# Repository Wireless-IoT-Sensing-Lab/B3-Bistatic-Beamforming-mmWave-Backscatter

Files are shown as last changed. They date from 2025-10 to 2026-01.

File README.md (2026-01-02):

#  $B^3$: Bistatic Beamforming for mmWave Backscatter

This repository provides the **implementation**, **hardware design**, and **experimental data** for the **Bistatic Beamforming Backscatter ($B^3$)** system — a high-frequency mmWave backscatter tag that enables efficient **beam-steered communication** between transmitters, receivers, and passive backscatter devices.

**📢 Please make sure to cite our paper if you use our hardware design, data, or implementation.**

Zhenzhe Lin, Yoon Chae, Mingyo Jeong, and Parth Pathak, "B^3: Bistatic Backscatter Beamforming for mmWave IoTs", ACM SenSys 2026. 

---

##  Overview

**$B^3$** demonstrates bistatic beamforming techniques that significantly improve **link robustness**, **signal strength**, and **energy efficiency** in mmWave backscatter systems.

This repository includes:
- **Hardware design files** for the custom bistatic backscatter tag and RF front-end — allowing researchers to **reproduce or extend** the hardware design for their own projects.  
- **Hardware Description** detailing each hardware component of $B^3$. Currently detailed descriptions and simulation results of $B^3$ Tx and Rx antennas are available.

---

## 📁 Repository Structure

| Folder | Description |
|:--|:--|
| **/Hardware Description/Antennas.md** | Antenna design documentation, radiation pattern plots, and beamforming test results. |
| **/Hardware Description/Hadamard Matrix.md** | Passive Beamforming Matrix Design documentation. |
| **/PCBO/Readme-PCBO.md** | This document offers a brief description about the PCBO package. |
| **/PCBO/DOCUMENTATION/** | This directory contains the manufacturing document |
| **/PCBO/BILL OF MATERIALS/** | This directory contains the BOM document for those who want to order their own $B^3$ hardware |

---

## Key Features

- **Tag Beamforming** – Coordinated transmit/receive beam control for optimized reflection and link quality.  
- **High-Speed Beam Switching** – Hardware supports up to **40 MHz** beam-switching rate.  
- **Modular Architecture** – Clean separation of control logic, RF front-end, and baseband processing.  
- **Open and Reproducible** – Provides all design files and documents to facilitate reproducibility and future research extensions.

---

**Wireless IoT Sensing Lab**  
[George Mason University]  
[http://www.phpathak.com/]

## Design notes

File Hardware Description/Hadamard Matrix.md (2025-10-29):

# $B^3$ Hadamard Passive Beamforming Matrix Design
A Butler matrix is the most commonly used passive beamformer because it creates a single sharp raditation pattern at a differnet angle depending on the excitation port. However, the angular coverage is typically narrower and, in many in-door applications, multi-beams show  as there is significantly less chance that all main lobes are blockecd by an object. 

**4×4 Hadamard**

A Hadamard matrix generates one center beam and N-1 dual beams at two symmetric angles ($\pm\theta$). This is because the matrix creates $180^\circ$ phase differences between adjacent element groups (or elements).

$$
H_4 =
\tfrac{1}{2}
\begin{bmatrix}
1 & 1 & 1 & 1 \\
1 & -1 & 1 & -1 \\
1 & 1 & -1 & -1 \\
1 & -1 & -1 & 1
\end{bmatrix}
$$

**4×4 Butler matrix**

A Butler matrix generates a pencil beam towards N different angles depending on the excitation port. To broaden the angular coverage, it requires a larget array size. Typically Butler matrix is very hard to implement beyond N=8.

$$
\mathbf{B}_4 =
\tfrac{1}{2}
\begin{bmatrix}
1 & 1 & 1 & 1 \\
1 & \mathrm{j} & -1 & -\mathrm{j} \\
1 & -1 & 1 & -1 \\
1 & -\mathrm{j} & -1 & \mathrm{j}
\end{bmatrix}
$$

## Quadrature hybrid coupler: a building block of a passive beamformer
A **quadrature hybrid** (a 3 dB, 90° branch-line coupler) splits input power equally into two output ports with a **90° phase difference**, while ideally isolating the fourth port. As passive beamformer highly rely on electrical delay differences and power splitting within the RF PCB, a quadrature hybrid coupler is the most important component in many passive beamformers.

**Ideal behavior (port order 1→2 through, 1→3 coupled, 4 isolated):**

<p align="center">
  <a href="https://github.com/user-attachments/assets/1daf9cee-dae2-4ece-bde0-42bf00902120">
    Quadrature hybrid coupler diagram
  </a><br/>
  <em>Figure 1. Quadrature hybrid (90°) coupler diagram. Source: Everything RF.</em>
</p>

$$
\mathbf{S}_\text{ideal}=\tfrac{1}{\sqrt{2}}
\begin{bmatrix}
0 & j & 1 & 0 \\
j & 0 & 0 & 1 \\
1 & 0 & 0 & j \\
0 & 1 & j & 0
\end{bmatrix}
$$

As shown in Figure 1, the four lines are **quarter-wave** sections; a common first cut uses horizontal (series) arms near $Z_0/\sqrt{2}\approx35.4~\Omega$ and vertical (shunt) arms near $Z_0\approx50~\Omega$ (final values are refined in EM to hit amplitude/phase targets). $S_{ideal}$ show the four-port S matrix that shows depending the input port, what are the two output ports and their relative phase differences.

**Quarter-wave physical length:**

$$
\ell_{90}=\frac{\lambda_g}{4}=\frac{c}{4f\sqrt{\varepsilon_\text{eff}}}
$$

As shown in Fig. 1, two $90^\circ$ traces at two different characteristic impedances ($Z_0/\sqrt{2}$, and $Z_0$) are the key design elements. Especially, at millimeter wave (mmWave) beyond 40GHz, $90^\circ$ delay lines are quite tricky to design because of the extremely short wavelength. When wavelength is very short, the $90^\circ$ lines tend to have very short length as compared to the width of the line to meet the impedance requirement. However, that causes phase inaccuracies due to the wide junctions in the vertical traces. To resolve the issue, we uses $Z_0=70.7 \Omega$.

---

**Fine-tuned Quadrature Hybrid Coupler Design**

| <a href="https://github.com/user-attachments/assets/1f7fc1f3-ea8b-4940-ac80-1be1fb2ef35a">Figure 2. The designed microstrip quadrature hybrid coupler</a> | <a href="https://github.com/user-attachments/assets/6d831ed9-ff66-4326-bbdb-1e40fa50c627">Figure 3. The S-parameter (Magnitude)</a> | <a href="https://github.com/user-attachments/assets/57edd651-2c44-4f71-8b04-aeb069404ad9">Figure 4. The S-parameter (Angle) of S21 and S31</a> |
|:--:|:--:|:--:|
| *Figure 2. Quadrature hybrid layout.*<br/>*3 dB, 90° branch-line.* | *Figure 3. S-parameter magnitude.*<br/>*\|S21\| and \|S31\| ≈ 3 dB; \|S11\|/\|S41\| show match & isolation.* | *Figure 4. S-parameter phase (S21 vs S31).*<br/>*Relative phase ≈ 90° across the band.* |

With 5-mil-thick Taconic TLX-8 substrate, line width of 0.1748mm yields the $70.7\Omega$ characteristic impedance while the $90^\circ$ trace width is around 0.85mm. The final length/height ratio is approximately 5; which is a better starting value for good $90^\circ$-phase delay design and -3dB power matching between S21 and S31. The horizontal and vertical branch 
line lengths are tuned to 0.7 and 0.75mm, respectively.

## Microstrip Crossover (using 70.7 Ω, 90° sections)

A **microstrip crossover** lets two transmission lines pass through each other on a single layer while maintaining match and isolation. One practical way at mmWave is to realize it with **$Z_0=70.7~\Omega$ quarter-wave ($90^\circ$) sections**, which provides an all-pass, single-layer structure without vias.

**Ideal 4-port behavior (1↔3, 2↔4), perfectly matched & isolated:**

$$
\mathbf{S}_\text{ideal} =
\begin{bmatrix}
0 & 0 & 1 & 0 \\
0 & 0 & 0 & 1 \\
1 & 0 & 0 & 0 \\
0 & 1 & 0 & 0
\end{bmatrix}
$$

In this ideal, **Port 1 → Port 3** and **Port 2 → Port 4** transmit with unity magnitude (and a defined reference phase), while the adjacent and opposite “non-through” ports are isolated.  
In practice, the 70.7 Ω, $\lambda_g/4$ sections set the electrical lengths so the tee/corner parasitics are absorbed into the phase budget, keeping return loss low and isolation high over the design band.

**Why 70.7 Ω and 90°?**  
The 70.7 Ω choice (i.e., $Z_0\sqrt{2}$ relative to a 50 Ω system) yields practical microstrip widths and allows the crossover to be synthesized as two quadrature paths that re-combine with the desired phase, so each line “sees” a matched through path while the orthogonal coupling is canceled.

---

**Fine-tuned microstrip crossover**

| <a href="https://github.com/user-attachments/assets/ef47e553-3f9d-4816-8d3a-24cd82cba011">Figure 5. The designed microstrip crossover with 70.7Ω, 90° lines</a> | <a href="https://github.com/user-attachments/assets/ffb73675-32cf-4931-bed4-af31b649efbe">Figure 6. S-parameters (magnitude) of the crossover</a> |
|:--:|:--:|
| *Figure 5. Microstrip crossover using $Z_0=70.7~\Omega$ quarter-wave sections.* | *Figure 6. S-parameters (magnitude): through paths (1→3, 2→4) near 0 dB with a small insertion loss; return/isolation low across the band.* |

The fine tuned crossover uses the same line width but the length was tuned to 0.84mm for a high return loss and a low insertion loss.

**Design remarks at 60 GHz:**  
Because $\lambda_g/4$ is short, the **physical $90^\circ$ length can approach pad and junction dimensions**, making the **phase extremely sensitive** to tiny geometry changes. The **70.7 Ω** target keeps line widths practical while balancing junction capacitances, helping the crossover stay matched and maintain isolation without resorting to multilayer vias.

---

## Our 4×4 Hadamard Beamformer Design

<p align="center">
  <a href="https://github.com/user-attachments/assets/50e50b09-91c7-4ba1-aac2-c0a97ddf9c74">
    Figure 7. Final Hadamard matrix design
  </a><br/>
  <em>Figure 7. Final Hadamard beamformer network.</em>
</p>

As shown in Fig. 7, the input ports are impedance-matched to $50~\Omega$ so the designed Hadamard network can connect to an **SP4T (single-pole, four-throw)** RF switch with lower mismatch loss. The output nodes are kept at $70.7~\Omega$ because the antenna is matched to $70.7~\Omega$. The transmission lines in each stage are fine-tuned to realize the target phase distributions. However, due to the impedance sensitivity of the quadrature hybrid coupler, avoiding impedance and phase imbalance is challenging and the tuning requires extensive EM simulations. Our final tuned S-parameter results are below.

---

### Port 1 excitation

| <a href="https://github.com/user-attachments/assets/39da352a-135a-4feb-a7c8-26a1ae7a1d36">Figure 8. S-parameters (magnitude) at Port 1 excitation</a> | <a href="https://github.com/user-attachments/assets/f6167672-8a27-4555-aa94-34bc9b3dc9fe">Figure 9. S-parameters (angle) at Port 1 excitation</a> |
|:--:|:--:|
| *Figure 8. S-parameters (magnitude), Port 1 excitation.* | *Figure 9. S-parameters (angle), Port 1 excitation.* |

### Port 2 excitation

| <a href="https://github.com/user-attachments/assets/ef67fb25-baa7-44d0-bc15-5e74a19fe3b7">Figure 10. S-parameters (magnitude) at Port 2 excitation</a> | <a href="https://github.com/user-attachments/assets/c1f02e03-8fff-4497-82d7-eeee9d60953a">Figure 11. S-parameters (angle) at Port 2 excitation</a> |
|:--:|:--:|
| *Figure 10. S-parameters (magnitude), Port 2 excitation.* | *Figure 11. S-parameters (angle), Port 2 excitation.* |

### Port 3 excitation

| <a href="https://github.com/user-attachments/assets/45a648ec-caec-4e7a-bd6a-d19dc9783381">Figure 12. S-parameters (magnitude) at Port 3 excitation</a> | <a href="https://github.com/user-attachments/assets/b7577b24-5453-41a5-850d-784c350be147">Figure 13. S-parameters (angle) at Port 3 excitation</a> |
|:--:|:--:|
| *Figure 12. S-parameters (magnitude), Port 3 excitation.* | *Figure 13. S-parameters (angle), Port 3 excitation.* |

### Port 4 excitation

| <a href="https://github.com/user-attachments/assets/426ba518-2663-4fc4-be7c-9da0dda3d2d7">Figure 14. S-parameters (magnitude) at Port 4 excitation</a> | <a href="https://github.com/user-attachments/assets/dfd6607b-c0a3-42eb-adc8-a2b0f24ce42b">Figure 15. S-parameters (angle) at Port 4 excitation</a> |
|:--:|:--:|
| *Figure 14. S-parameters (magnitude), Port 4 excitation.* | *Figure 15. S-parameters (angle), Port 4 excitation.* |

**Summary at 60 GHz:** The simulated phase imbalance is approximately within $5^\circ$ at 60 GHz (worst case), and the typical amplitude imbalance is within **1.0 dB** at 60 GHz.

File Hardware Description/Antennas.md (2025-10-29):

# $B^3$ Antenna Designs
Wide beam-coverage is the key factor of successful deployment of $B^3$. For a broader beam coverage and faster beam searching, we choose 4X4 Hadamard beamforming matrix.

$$
H_4 =
\tfrac{1}{2}
\begin{bmatrix}
1 & 1 & 1 & 1 \\
1 & -1 & 1 & -1 \\
1 & 1 & -1 & -1 \\
1 & -1 & -1 & 1
\end{bmatrix}
$$

When a four-linear array antenna is fed by a passive Hadamard beamforming matrix that has the voltage and phase distribution as $H_4$, the array antenna could generate four beam patterns with one center beam and three dual split-beams at two symmetric angles $\pm\theta$.

This document focus on sharing design details of the array antennas we designed for $B^3$. The design of a passive Hadamard beamforming network will be discussed in a separate document.

# Rx Antenna Design

This chapter describes the receive (Rx) antenna used in $B^3$: a single rectangular microstrip patch operating in $TM_{10}$. The choice is deliberate—compared with small arrays it occupies less area, is easy to integrate above a solid ground, and, when pointed broadside at the service region, exhibits a wide, smooth main lobe that behaves like a **pseudo-omnidirectional** pattern for reception.

---

## Electromagnetic model and first-cut dimensions

The patch is treated as a resonant $TM_{10}$ cavity with fringing fields at the radiating edges. Standard closed-form formulas provide a reliable starting point (SI units).

**Patch width (broadside gain and bandwidth improve with larger $W$):**

$$
W=\frac{c}{2f_r}\sqrt{\frac{2}{\varepsilon_r+1}}
$$

**Effective permittivity (accounts for fringing into air):**

$$
\varepsilon_{\mathrm{eff}}
=\frac{\varepsilon_r+1}{2}
+\frac{\varepsilon_r-1}{2}\left(1+12\frac{h}{W}\right)^{-1/2}
$$

**Fringing length extension (per edge):**

$$
\Delta L
=0.412\,h\;
\frac{\left(\varepsilon_{\mathrm{eff}}+0.3\right)\left(\frac{W}{h}+0.264\right)}
{\left(\varepsilon_{\mathrm{eff}}-0.258\right)\left(\frac{W}{h}+0.8\right)}
$$

**Effective and physical length (sets the resonance):**

$$
L_{\mathrm{eff}}=\frac{c}{2f_r\sqrt{\varepsilon_{\mathrm{eff}}}}
$$

$$
L=L_{\mathrm{eff}}-2\Delta L
$$

**Ground plane sizing (keeps the pattern stable):**

$$
W_g \gtrsim W+6h,\qquad L_g \gtrsim L+6h
$$

*Symbols:* $c$ speed of light; $\varepsilon_r$ substrate relative permittivity; $h$ substrate thickness; $W,L$ patch width/length; $f_r$ target resonance.

---

## Why a single patch is a good pseudo-omni **receiver**

Mounted with its broadside facing the coverage region, a rectangular patch has wide half-power beamwidths in both principal planes (commonly on the order of $60^\circ$ – $90^\circ$ depending on $W/L$ and substrate). The integral ground plane suppresses the back lobe and shields cables and electronics, so most sensitivity is directed into the *forward* hemisphere. In dense or indoor environments, multipath and angular spread further “fill in” nulls, making the azimuth response functionally omni-like for receiving while retaining the patch’s compact, low-profile form.

A small footprint does not imply a small receive aperture. Using

$$
A_e=\frac{\lambda^2 G}{4\pi},
$$

a typical broadside gain of $G\approx 6\text{–}8$ dBi yields ample effective area for robust SNR without resorting to an array—useful for $B^3$, where simplicity and repeatability matter.

---

## a 100 Ω inset feed impedance matching

We purposely set the feed point along the patch’s symmetry line where the input resistance is **about $100~\Omega$**. This choice keeps the notch relatively **shallow**, so the $TM_{10}$ current sheet is disturbed less, and the narrower microstrip at the radiating edge adds **less capacitive loading**. Therefore, it preserves the clean broad beam we want for pseudo-omni Rx.

Along the symmetry line, the input resistance varies with inset depth $y$ (measured from the radiating edge) as

$$
R_{\mathrm{in}}(y)=R_{\mathrm{edge}}\cos^{2}\\left(\frac{\pi y}{L}\right).
$$

Solving for a $100~\Omega$ target gives a first-cut inset:

$$
y=\frac{L}{\pi}\cos^{-1}\\sqrt{\frac{100}{R_{\mathrm{edge}}}}.
$$

Here $R_{\mathrm{edge}}$ is the resistance right at the edge ($y=0$); a quick EM model or a prior build provides a good estimate. Because the inset is shallow at $100~\Omega$, small tweaks (on the order of a millimeter for typical boards) smoothly bring $R_{\mathrm{in}}$ to target with minimal impact on resonance or pattern.

To choose the **feed and notch widths**, size the microstrip line on the same substrate for approximately $100~\Omega$ and make the slot just wide enough to admit that line without excessive fringing. For the line, use the usual microstrip relations (Hammerstad–Jensen) to relate width $W_f$ over height $h$ to $Z_0$; the effective permittivity of the line is

$$
\varepsilon_{\mathrm{eff,line}}
=\frac{\varepsilon_r+1}{2}
+\frac{\varepsilon_r-1}{2}\left(1+12\frac{h}{W_f}\right)^{-1/2}.
$$

We chose the inset with the same as 100-ohm trace width ($W_{100Ω}$) and fine-tuned the inset length so that we have impedance matching at 100Ω. Then, using a quarter-wave transformer (using a 84Ω quarter-wave line), 70.7Ω impedance matching was implemented.

---

## The fine-tuned Rx antenna design

| <a href="https://github.com/user-attachments/assets/20760015-aa49-41a0-b14a-b6fbbe27c5c2">Rx Antenna</a> | <a href="https://github.com/user-attachments/assets/3bfa50a5-b682-4d31-af23-55340dbb59ba">Rx Antenna S11</a> |
|:--:|:--:|
| *Figure 1. Rx antenna (rectangular microstrip patch).* | *Figure 2. Return loss (S11) of the Rx patch).* |

Fig. 1 shows the finalized Rx microstrip patch antenna with 100Ω-line inset match and it shows a impedance bandwidth of approximately 2GHz (59.2-61.2GHz) which corresponds to a 3.33% fractional bandwidth.

### Design summary and parameters
The fine-tuned design parameters are itemmized and listed below.

**Substrate:** Taconic TLX-8, 5 mil (0.127 mm) core.

**Patch geometry:**  
- Patch width $W_{\text{patch}} = 1.87$ mm  
- Patch length (height) $H_{\text{patch}} = 1.45$ mm  

**Inset feed (100 Ω target at the feed point):**  
- Inset width $W_{\text{inset}} = W_{100\Omega} = 0.0762$ mm  
- Inset depth $H_{\text{inset}} = 0.4$ mm  
rent sheet, and reduces capacitive loading at the radiating edge—helpful for preserving a broad, smooth receive pattern (pseudo-omni) while maintaining a robust landing area.

**Microstrip lines on TLX-8 (same stackup)**  
Each listed length is a 90° electrical length (i.e., $\lambda_g/4$) at the design frequency for that microstrip line width.

| Line Impedance | Width (mm) | Length for 90° (mm) |
|:--:|:--:|:--:|
| $100~\Omega$ | **0.0762** | **0.895** |
| $84~\Omega$ | **0.1189** | **0.882** |
| $70.7~\Omega$ | **0.1745** | **0.8725** |

### Far-field performance

| <a href="https://github.com/user-attachments/assets/149b7673-c69e-4aa8-9812-db17473b345e">Rx antenna far-field radiation pattern at 60GHz</a> | <a href="https://github.com/user-attachments/assets/3228c77c-a41b-43cc-a67c-5e6e0dabcde0">Rx antenna peak realized gain over frequency</a> |
|:--:|:--:|
| *Figure 3. Rx antenna far-field radiation pattern at 60 GHz.* | *Figure 4. Rx antenna peak realized gain versus frequency.* |

The fine-tuned Rx antenna shows the peak realized gain of 7.83dBi at 60GHz and the Realize gain is above 6.5dBi within the impedance bandwidth. This allows the tag can be reachable by a distant nodes while allowing a moderate angular beam covereage.

# Tx Antenna Array Final Design

While Rx antenna requires pseudo-omni-directional operation, a $B^3$ Tx antenna requres higher gain as wider and selected beam. For the goal of $B^3$, a Hadamard linear switched array antenna is a perfect choice as it offers much wider beam coverage with high gain. Using the Rx antenna's dimensions as a starting point, the array antenna is tuned. For a compact design, we limited the liear array size to 4, while each element is a 4X1 series patch antenna array to maximize the gain for a long distance communication. The 4X4 array antenna was fine-tuned using CST Microwave Studio 2025 time domain solver. The element to element spacing (3.131mm) is equal to a guided-wavelength in a 5-mils-thick Taconic TLX-8 substrate. The physical spacing is also corresponding to a 0.63 free space wavelength, which offers a moderate gain as well as moderate grating lobe rejection.

## 4X1 Subarray element

| <a href="https://github.com/user-attachments/assets/dcec094f-dd77-4e3d-b643-cf9723ec8e4e">Figure 5. The fine-tuned 4×4 array antenna design</a> | <a href="https://github.com/user-attachments/assets/6ad3ba4c-07f6-4187-838d-056588f62e03">Figure 6. The simulated far-field radiation pattern of a linear 4×1 patch array element in the 4×4 array antenna</a> |
|:--:|:--:|
| *Figure 5. The fine-tuned 4×4 array antenna design.* | *Figure 6. Simulated far-field radiation pattern of a linear 4×1 patch array element within the 4×4 array.* |

<p align="center">
  <a href="https://github.com/user-attachments/assets/e789543e-79c1-4c7d-8468-cfeab6352358">
    Figure 7. Reflection coefficient of 4×1 patch array element
  </a><br/>
  <em>Figure 7. Reflection coefficient of a 4×1 patch array element.</em>
</p>

The fine-tuned antenna subarray is designed with a 100Ω feed line with 0.9mm feed line length which points beam towards the lower elevation angle for a good impedance matching within the operating frequency. The nominal patch antenna size is decided $(W_{patch_{norm}}, H_{patch_{norm}})$ = (1.87, 1.45) [mm]. And the width ratio for the each element within the subarray is tuned to be (0.8, 1, 1, 0.8) while 1 corresponds to $W_{patch_{norm}}$. As a result, the sub-array has almost 10% fractional bandwidth (6GHz impedance bandwidth from 57.15GHz to 63.24GHz). The subarray peak realized gain is approximately 10.8dBi.

## 4X4 Tx Linear Array Simulation Result

| <a href="https://github.com/user-attachments/assets/af10bab1-baf5-4497-9209-0f0cea8df004">$B^3$ Tx switched array final design</a> | <a href="https://github.com/user-attachments/assets/3243bb02-bac7-429b-8c7f-00495b132f20">Reflection coefficient of the Tx antenna</a> |
|:--:|:--:|
| *Figure 8. B^3 Tx switched-array final design.* | *Figure 9. Reflection coefficient (S11) of the Tx antenna.* |

We integrated the designed microstrip 4X4 Hadamard matrix passive beamforming matrix and the 4X4 linear patch array antenna so that we can switch beams electrically for the demonstration of $B^3$. The impedance bandwidth of the final araay is similar to that of the linear array element but slightly wider. Now, depending on which input port we excite the RF signal, Hadamard beamformer generates four different beam shapes as below.

| <a href="https://github.com/user-attachments/assets/e8b0e049-3c50-40f7-9efa-925ca538c30a">$B^3$ Tx beam pattern 1</a> | <a href="https://github.com/user-attachments/assets/f2b9e04a-1b89-46d9-85ee-22951b230ed9">$B^3$ Tx beam pattern 2</a> |
|:--:|:--:|
| *Figure 10. B^3 Tx beam pattern 1.* | *Figure 11. B^3 Tx beam pattern 2.* |

| <a href="https://github.com/user-attachments/assets/9cbb3155-705d-4107-b4fe-1506d67907a0">$B^3$ Tx beam pattern 3</a> | <a href="https://github.com/user-attachments/assets/580e1c96-9047-4385-9211-b26c9513bb8c">$B^3$ Tx beam pattern 4</a> |
|:--:|:--:|
| *Figure 12. B^3 Tx beam pattern 3.* | *Figure 13. B^3 Tx beam pattern 4.* |

The 4th beam pattern is the center beam and this beam patterns is created when the phase output of the beamformer is the same for all 4 output ports. Then 1st, 2nd, and 3rd beams have two main lobes and the beam pattern is symmetric to the broadside. The peak gain at beam#4 is approximately 14.6dBi at 60GHz (15.5dBi @ 62.5GHz), and the split beams have approximately 3dB lower gain.

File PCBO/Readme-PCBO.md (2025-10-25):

$B^3$ - PCB Order Package

This folder contains the required files for a PCB order. The package includes
1. Documentation: layer views for each design layers, stack-up descriptions
2. DXF File
3. Gerver package - Pick and Place file is included for assembly orders
4. Bill of Material (BOM)

Please make sure choose a manufacturer that can handle RF PCB materials.

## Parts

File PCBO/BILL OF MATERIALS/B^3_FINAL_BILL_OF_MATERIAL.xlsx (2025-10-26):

 | Bill of Materials
 |  |  |  |  |  |  | 2175 Salk Avenue
 | Project Title: | Bill of Materials for BOM Document [B^3_FINAL.BomDoc] |  |  |  |  | Suite 200
 | Project File Name: | B^3_FINAL.PrjPcb |  |  |  |  | Carlsbad, CA 92008
 | Assembly Variant: | None |  |  |  |  | USA
Part Number | Description | Designator | Manufacture | Manufacture Part Number | Supplier | Supplier Part Number | Supplier Unit Price | Quantity
CMP-2010-01498-2 | Chip Multilayer Ceramic Capacitors for General Purpose, 0201, 100pF, C0G, 30ppm/°C, 5%, 50V | C1, C2, C3, C4, C5, C6, C7, C8, C9, C10, C11 | Murata | GRM0335C1H101JA01D | Mouser | 81-GRM0335C1H101JA1D | $0.01 | 11
CMP-001-00083-1 | Silicon Capacitor 100nF 11VDC 0402 | C12 | Murata | 935155424610-T3N | DigiKey | 490-935155424610-T3NCT-ND | $7.03 | 1
CMP-001-00085-1 | Silicon Capacitor NC 11VDC 0402 | C13, C14 | DNI |  |  |  |  | 2
CMP-2008-04245-1 |  | C15 | Murata | GRM1555C1H100JA01D | DigiKey | 490-5921-1-ND | $0.10 | 1
CMP-00025-00017-1 | RF Connector, 1 Contact(s), Male, Board Mount, Surface Mount Terminal, Receptacle | J1 | HIROSE ELECTRIC | U.FL-R-SMT-1(10) | Newark | 50P8856 | $1.11 | 1
CMP-002-00075-1 | 2.54mm (0.1") Pitch SIL Horizontal SMT Socket Assembly, selective gold + tin (Tape & Reel packing), 5 contacts | J2 | Harwin | M20-7910542R | Farnell | 3226216 | $0.96 | 1
CMP-002-00076-1 | 2.54mm (0.1") Pitch SIL Horizontal SMT Socket Assembly, selective gold + tin (Tape & Reel packing), 5 contacts | J3 | Harwin | M20-7910542R | Farnell | 3226216 | $0.96 | 1
CMP-00025-00005-11 | 4X4 Hadamard Matrix operating at 60GHz | M1, M5 | PCB Embedded - DNI |  |  |  |  | 2
CMP-00025-00004-15 | 4X4 Linear Patch Antennas operating at 60GHz | M2, M6 |  |  |  |  |  | 2
CMP-00025-00006-3 | 60GHz 1 by 1 Patch Antenna | M3 |  |  |  |  |  | 1
CMP-00025-00007-4 | 60GHz 15dB Directional Coupler | M4 |  |  |  |  |  | 1
CMP-009-00178-3 | Fixed Resistor, Thin Film, 0.05W, 50ohm, 37V, 5% +/-Tol, 100ppm/Cel, Surface Mount, 0402 | R1 | Vishay | CH0402-50RJFT | Mouser | 71-CH0402-50RJFT | $6.54 | 1
CMP-2002-08343-2 | RES Thick Film, 1Ω, 1%, 0.063W, 200ppm/°C, 0402 | R2 | Vishay | CRCW04021R00FNED | Newark | 29AH9417 | $0.02 | 1
CMP-009-00177-1 | Chip Resistor, NC, +/-1 %, 63 mW, -55 to 155 degC, 0402 | R3 | Bourns | CR0402-FX-1202GLF | Newark | 33AK7333 | $0.002 | 1
CMP-2002-00022-2 | RES Thick Film, 470Ω, 1%, 0.063W, 100ppm/°C, 0402 | R4 | Vishay | CRCW0402470RFKED | Newark | 72M6795 | $0.01 | 1
CMP-011-00013-5 | 1 GHz to 60 GHz, Reflective, Silicon SP4T Switch | S1, S2 | Analog Devices | ADRF5054BCCZN | Mouser | 584-ADRF5054BCCZN | $133.69 | 2
CMP-00025-00016-1 | RF Switch SPDT 1GHz to 60GHz 32dB 12-Pin LGA EP T/R | U1 | Analog Devices | ADRF5032BCCZN | Mouser | 584-ADRF5032BCCZN | $129.45 | 1
CMP-00025-00014-1 | RF Detector 100MHz to 70000MHz 4.5dBm 8-Pin DFN EP T/R | U2 | Analog Devices | LTC5597HDC#TRMPBF | DigiKey | 505-LTC5597HDC#TRMPBFCT-ND | $104.22 | 1
 |  |  |  |  |  |  | $384.11 | 32
Approved |  | Notes

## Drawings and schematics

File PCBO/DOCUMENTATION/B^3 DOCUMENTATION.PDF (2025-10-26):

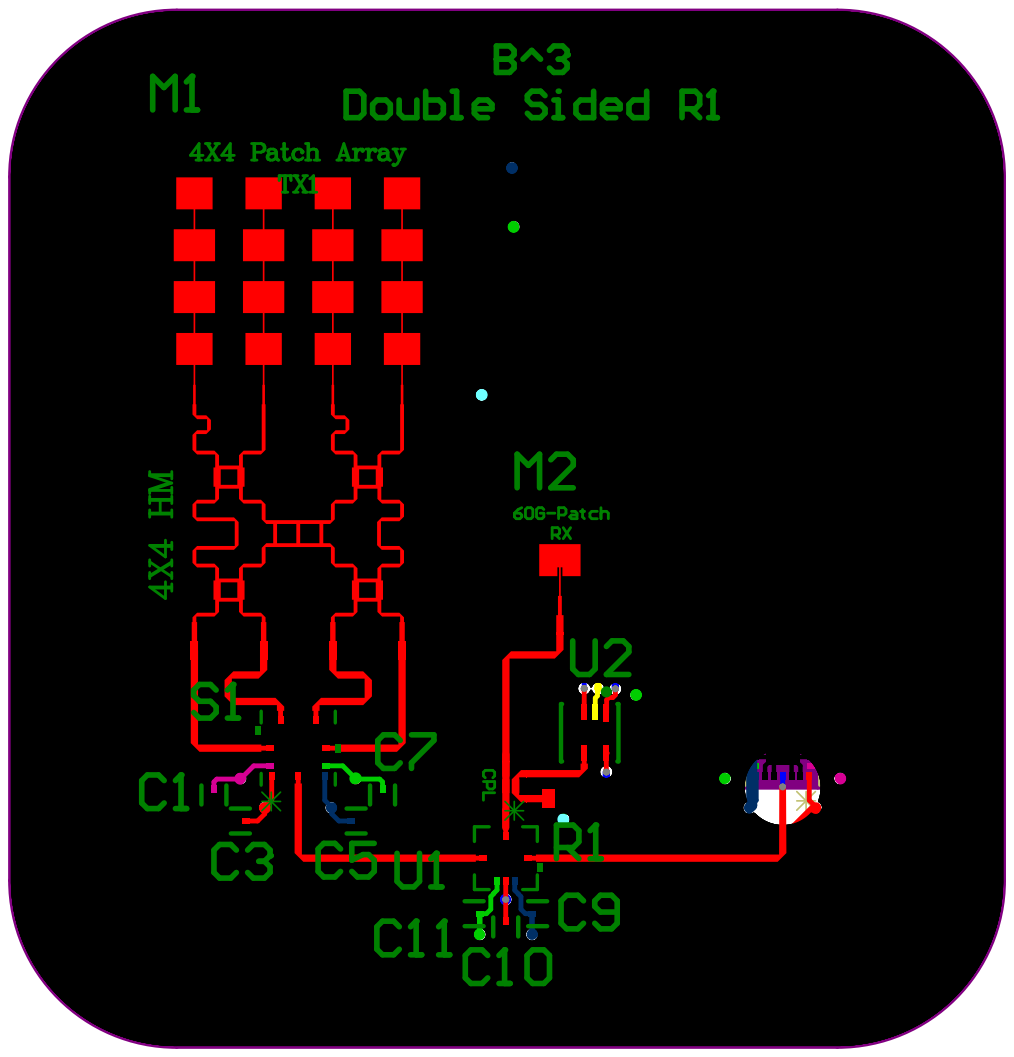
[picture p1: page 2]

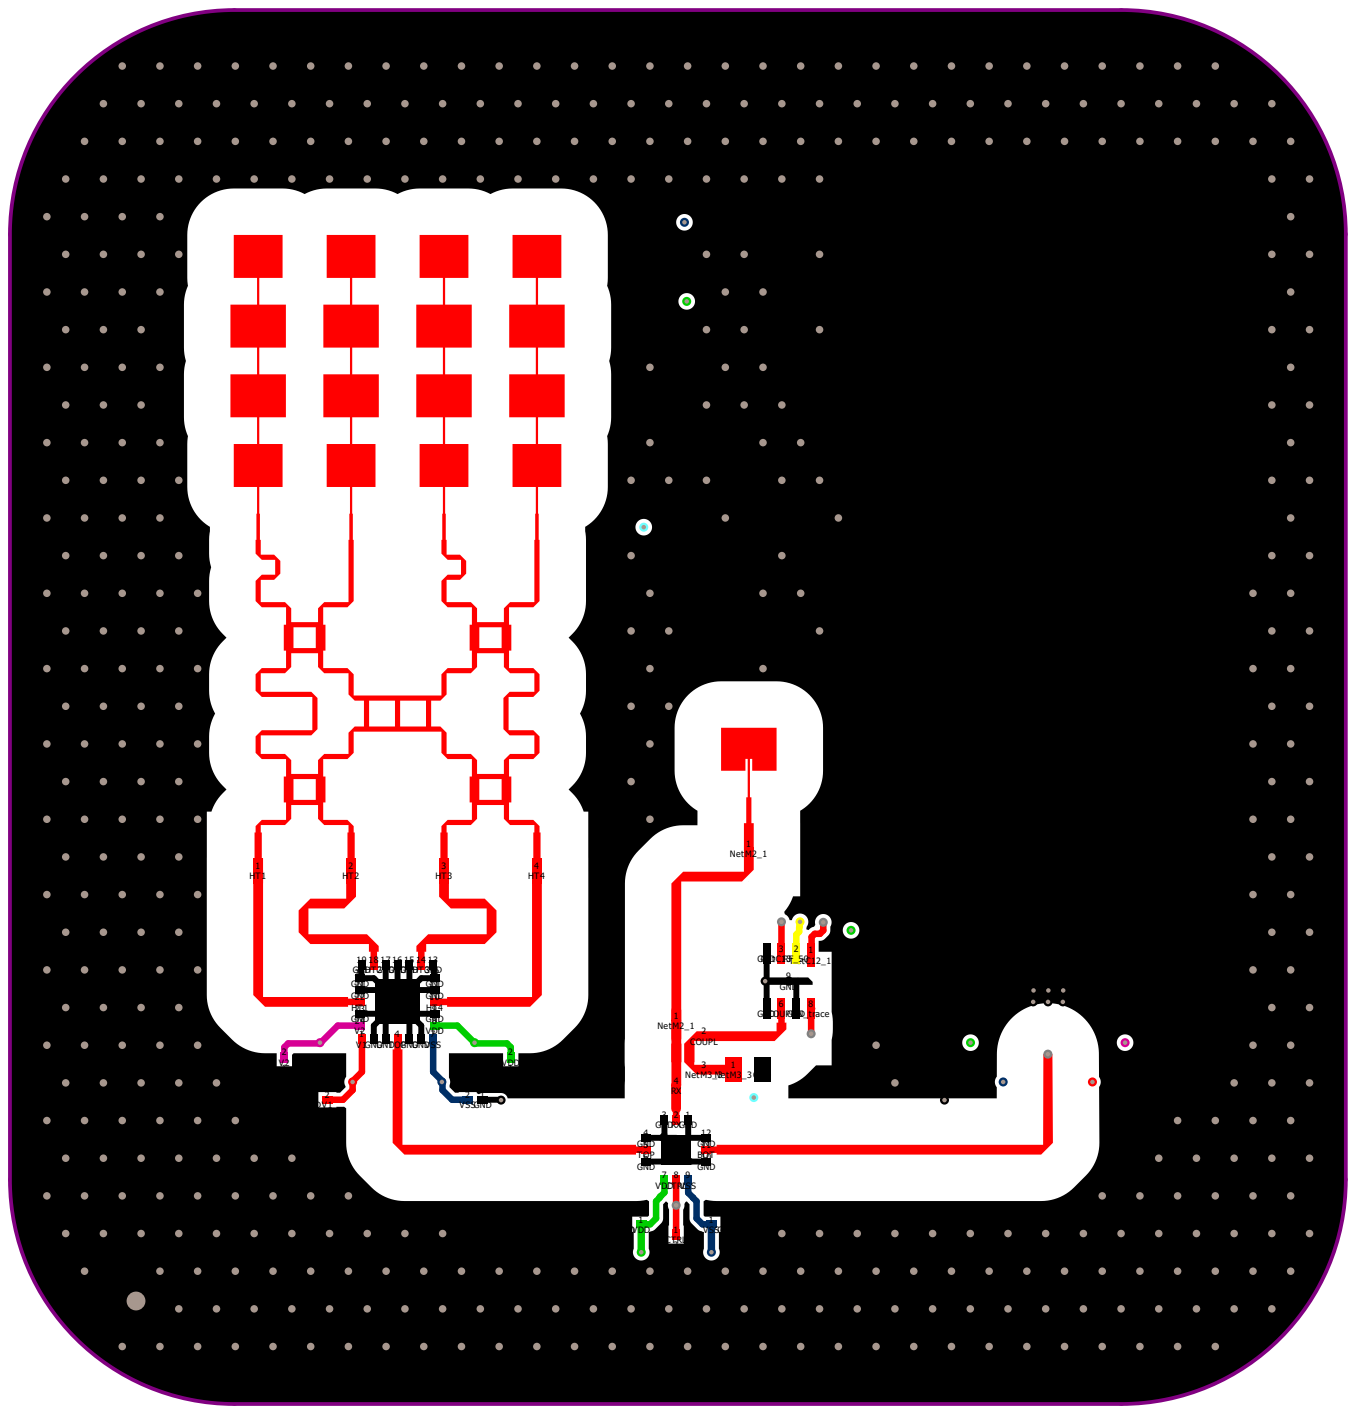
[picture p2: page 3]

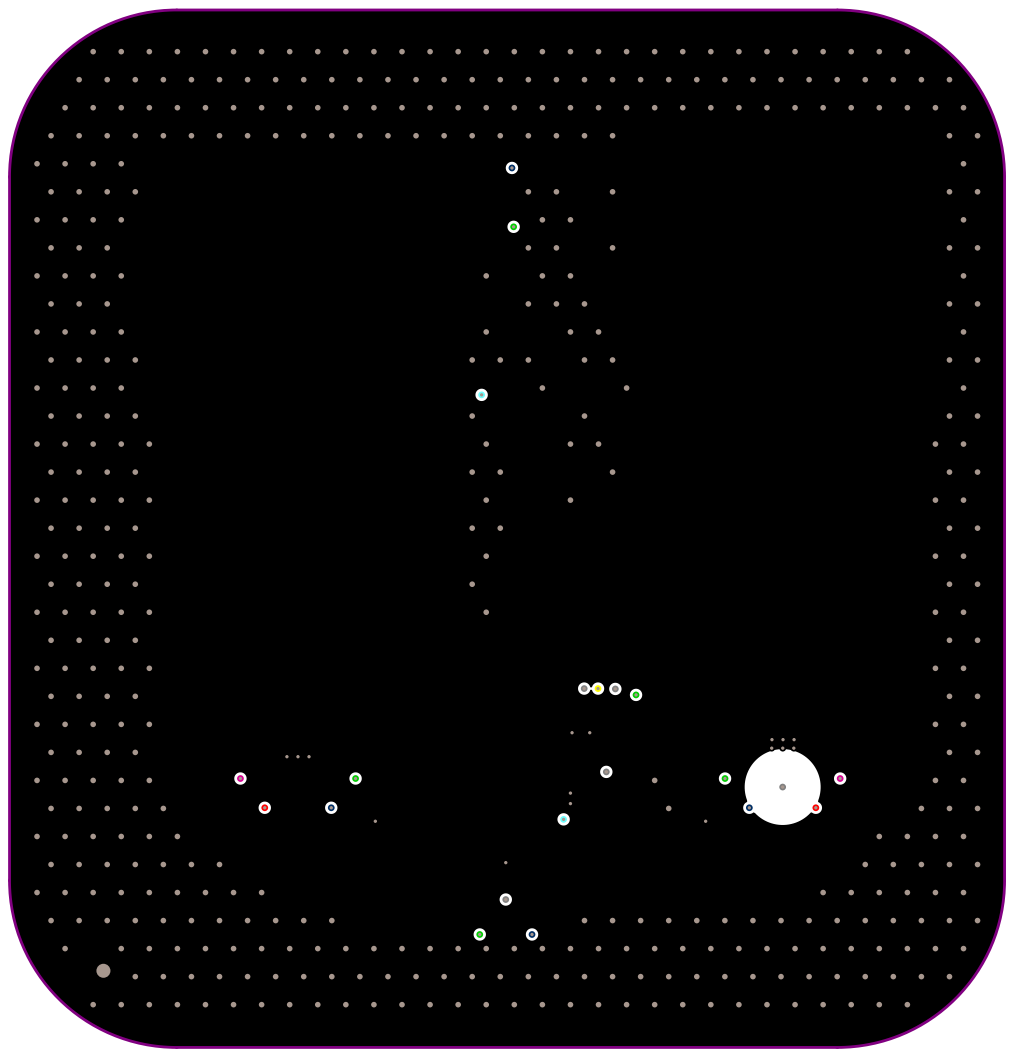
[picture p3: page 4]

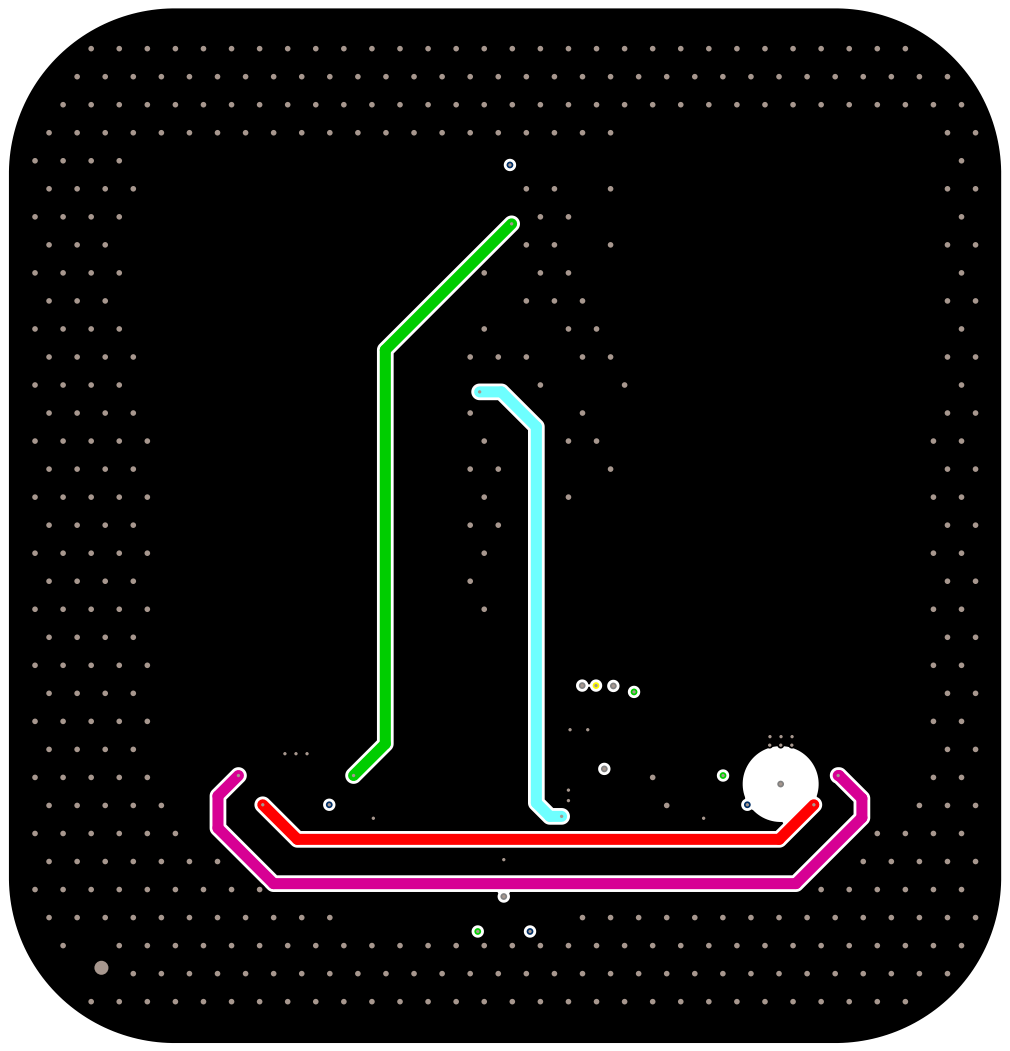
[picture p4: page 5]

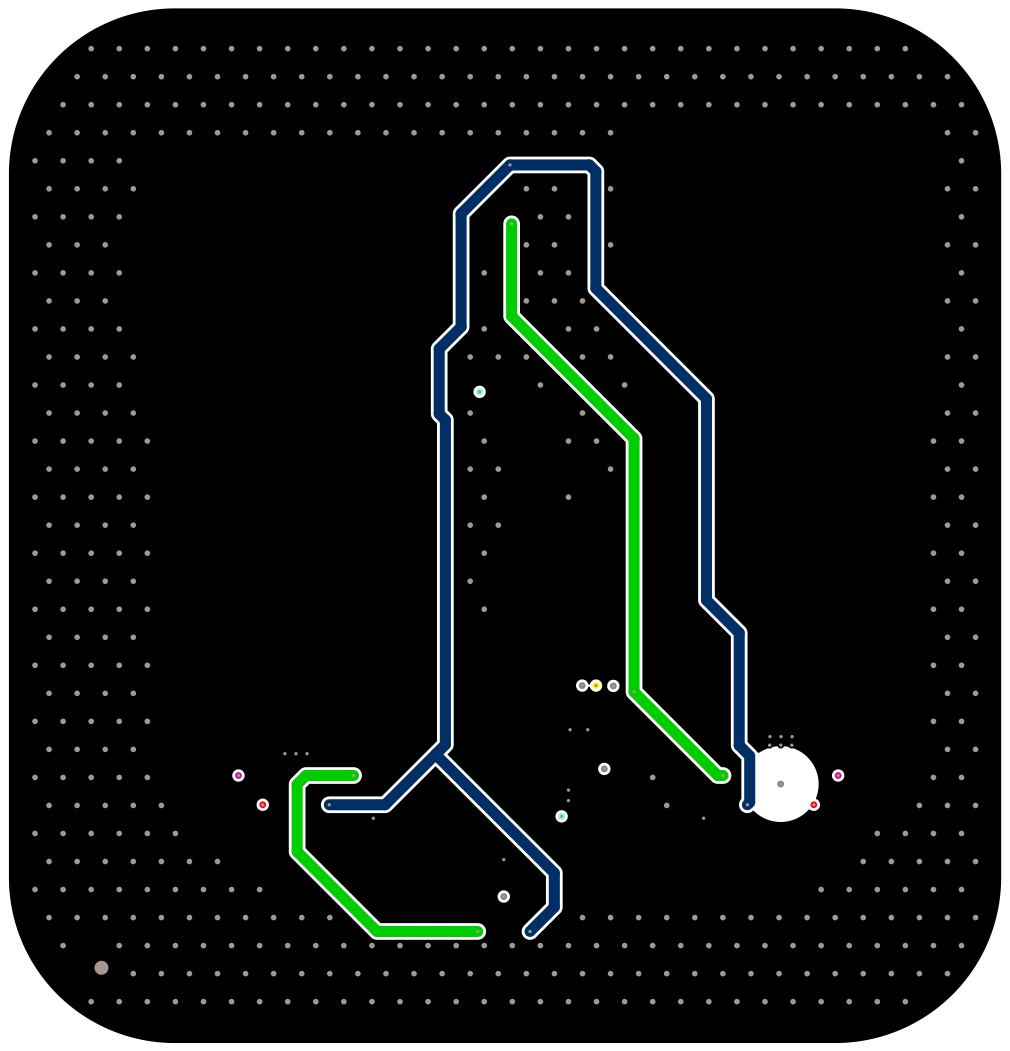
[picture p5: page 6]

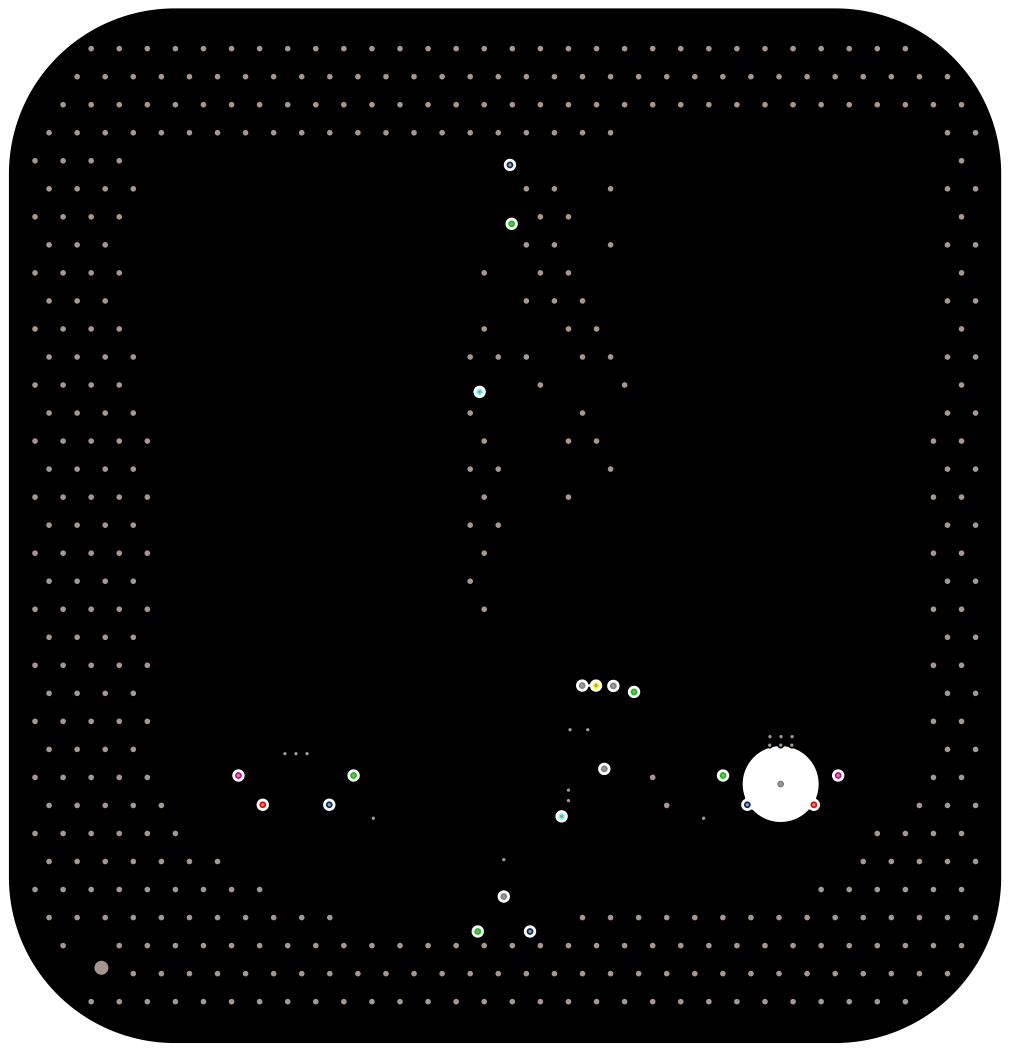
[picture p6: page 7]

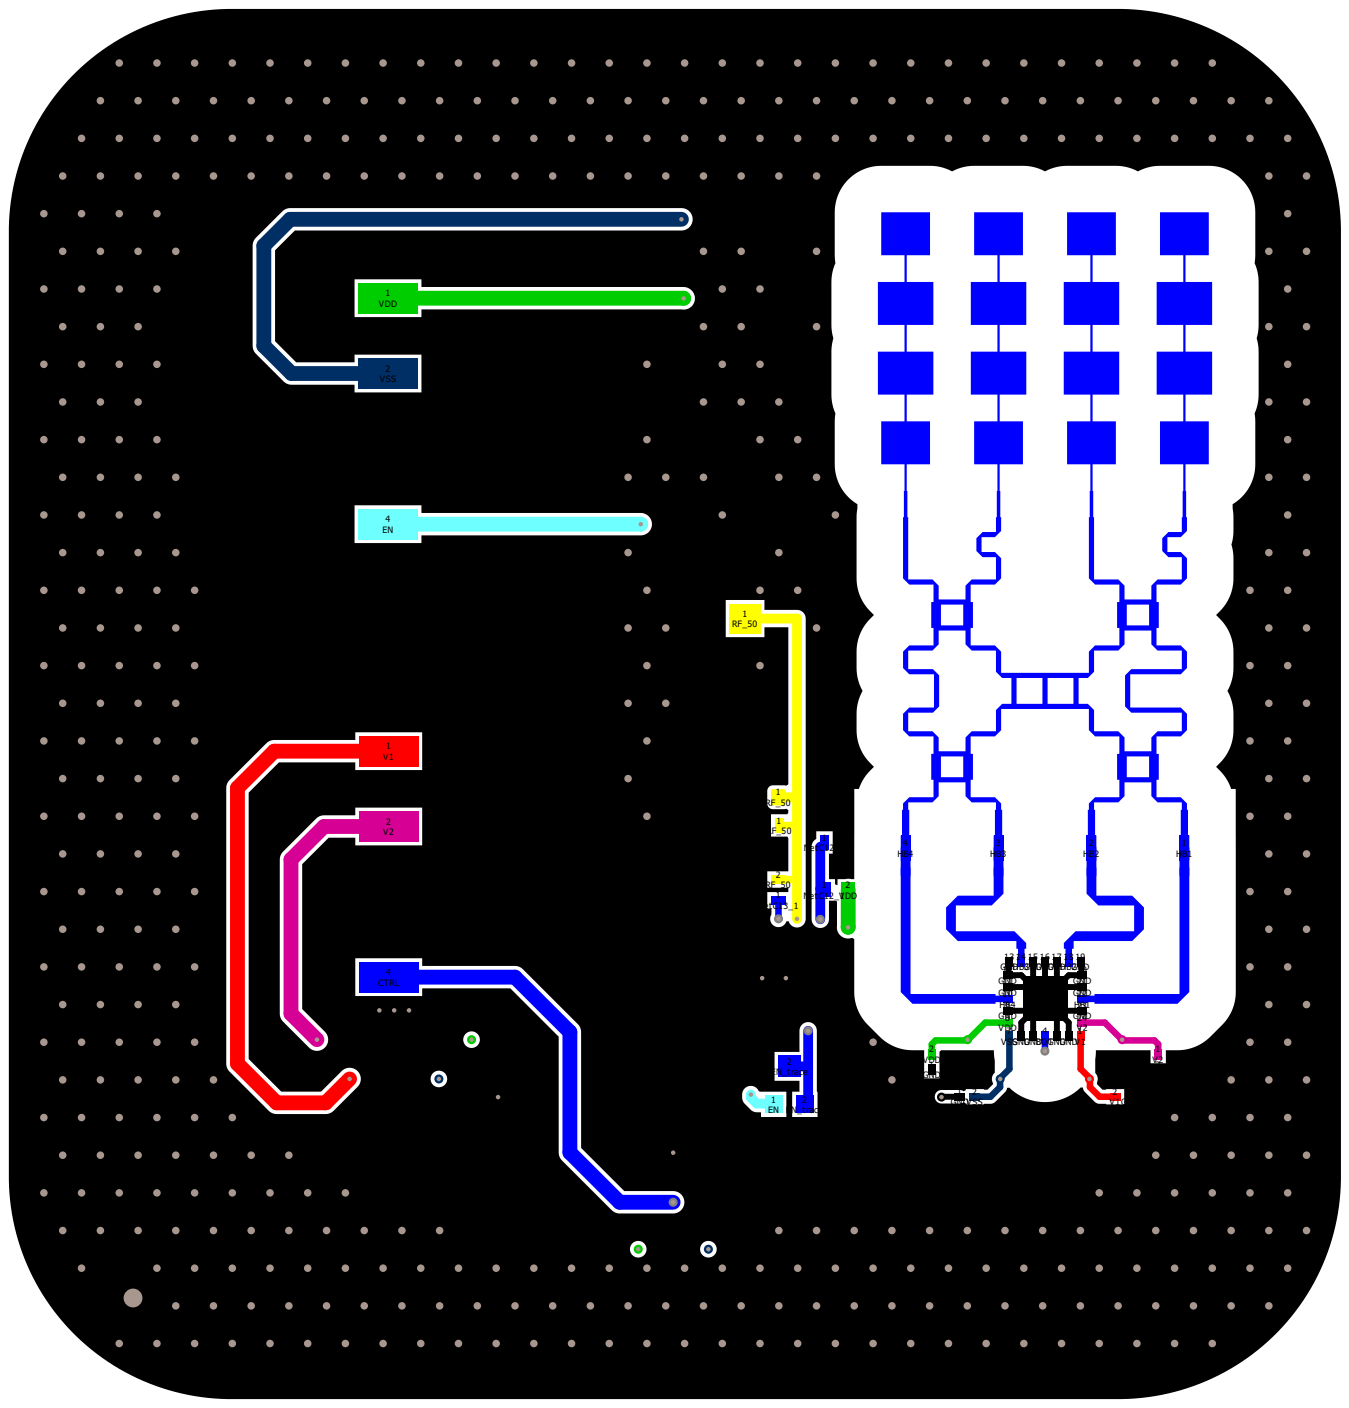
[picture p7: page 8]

1 GND | 2

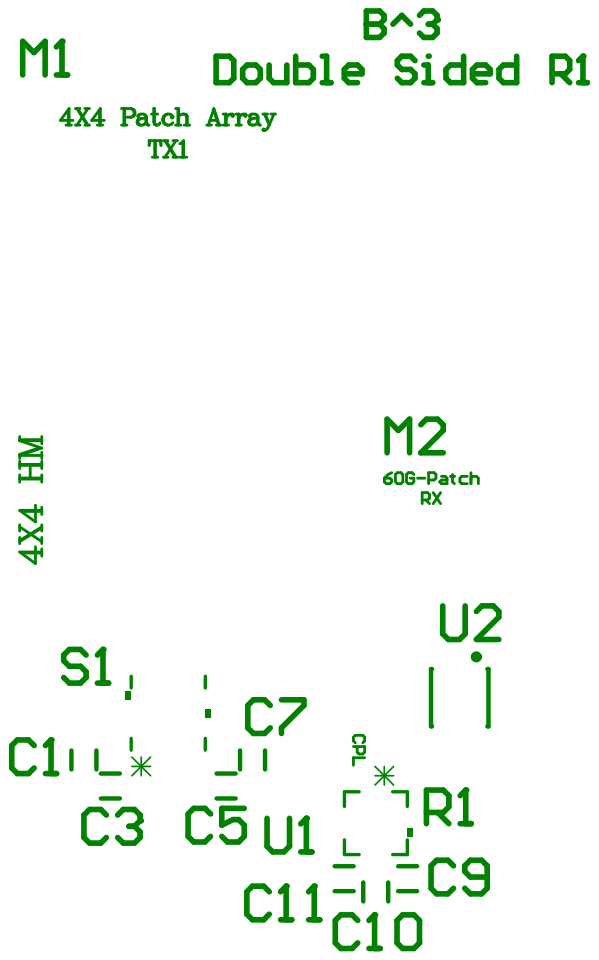
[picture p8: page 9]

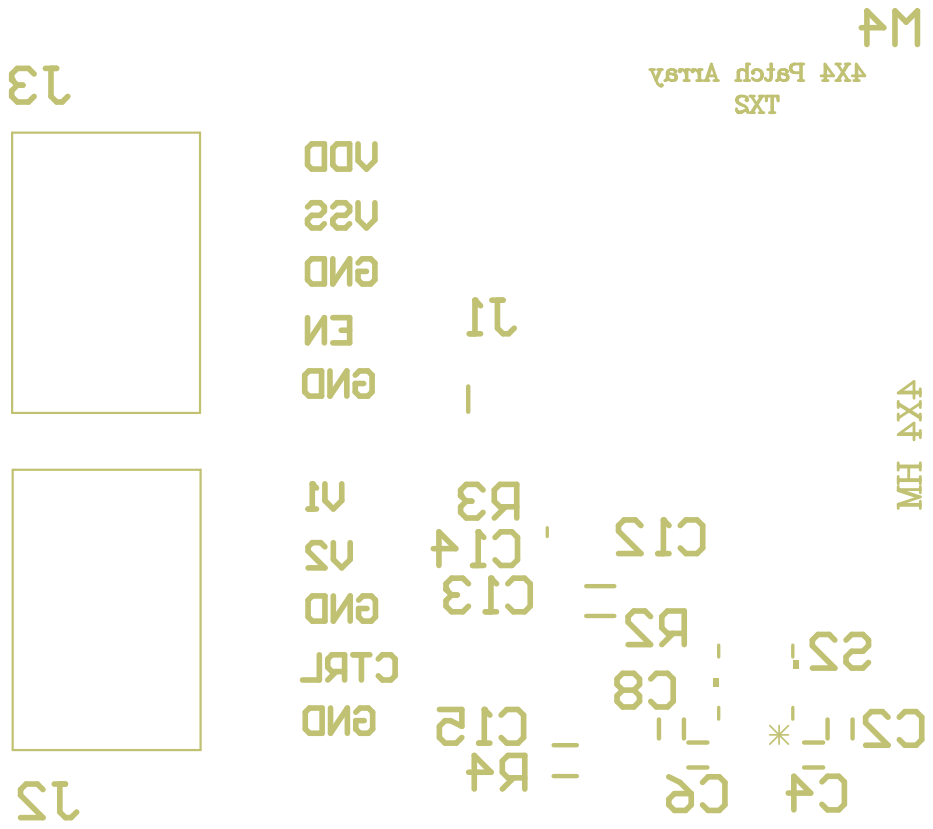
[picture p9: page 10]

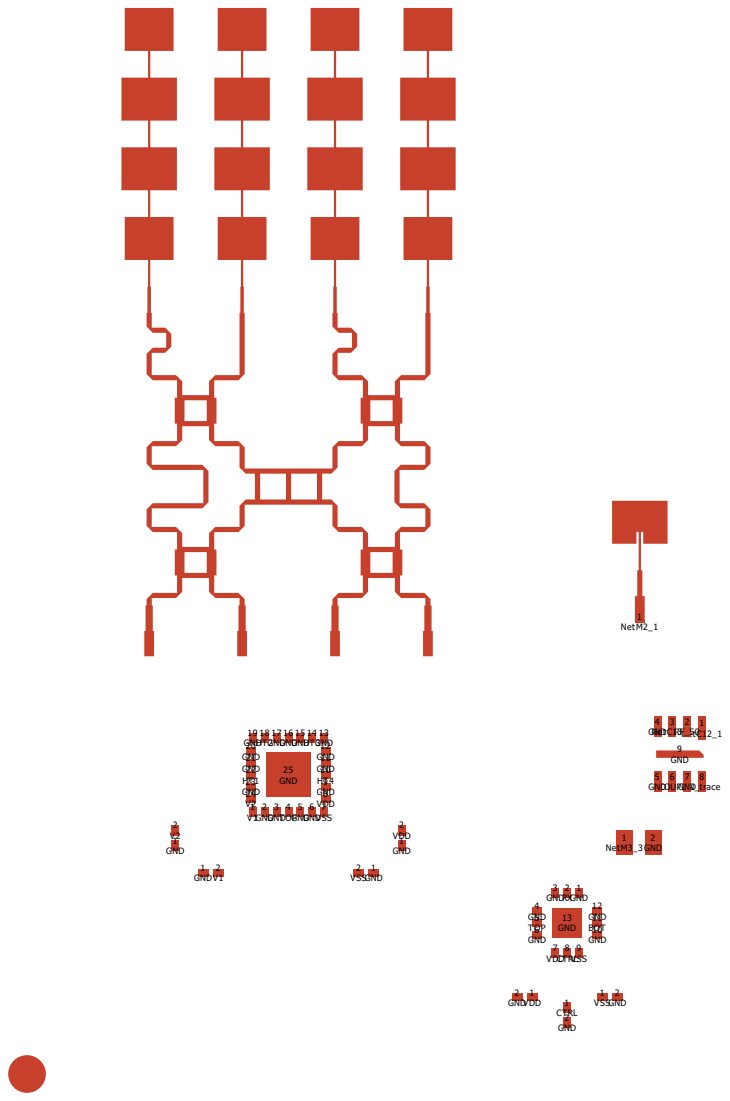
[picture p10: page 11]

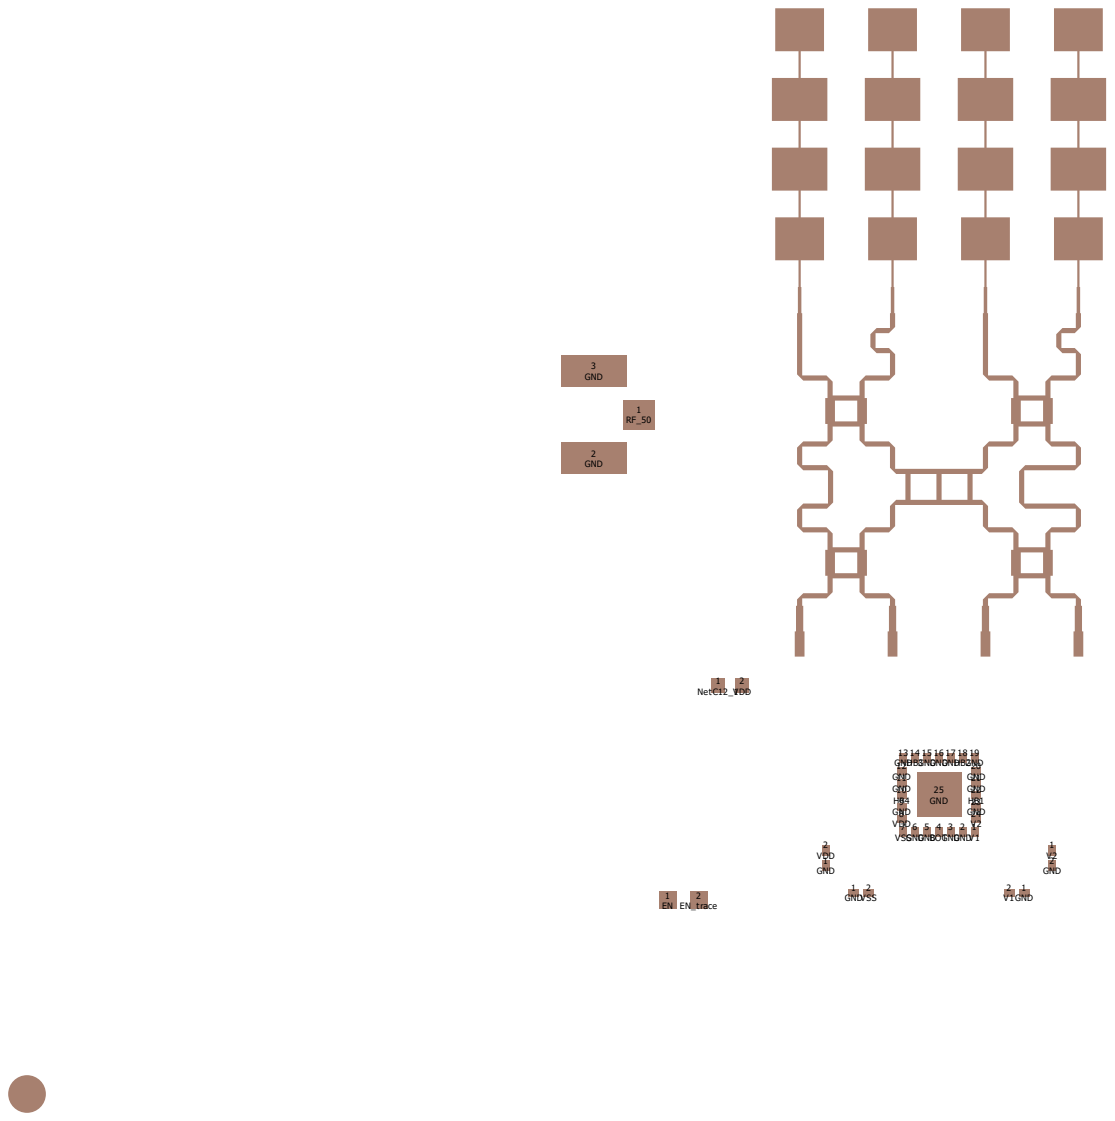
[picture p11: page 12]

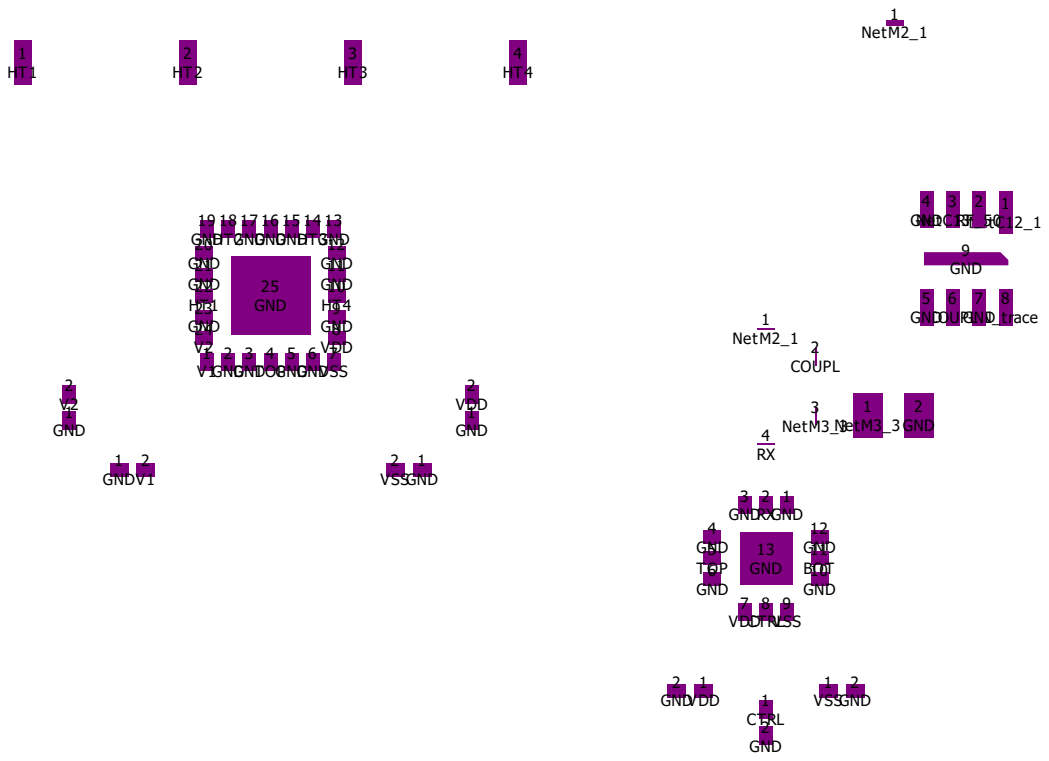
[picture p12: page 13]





VDD 1 VSS 2 GND 3 EN 4 GND 5 J3



6 0 G Hz_ 5 0 o hm_ | s tri p i


18 ND 19 GND 20 GND 21 RF1 22 GND 23 V2 24

GND 12 GND 13 RF3 14 GND 15 GND 16 GND 17 RF2

RFC 2
GND 3 | | PWR
GND 4
RF1 5
GND 6

Rx SPDT switch chooses between top and bottom SP4T switches.
For that, user should switch between CTRL high and low.


Stack Up | Layer Stack
Layer | Board Layer Stack | Name | Material | Thickness | Constant
1 | | Top Overlay | | 0mil
2 | | Top Solder | Solder Resist | 0.4mil | 3.5
3 | | Top Layer | | 0.354mil
4 | | Dielectric 1 | Taconic TLX-8 | 5mil | 2.55
5 | | Layer 1 | CF-004 | 0.689mil
6 | | Dielectric 2 | FR-4 | 2.3mil | 4.4
7 | | Layer 2 | CF-004 | 0.689mil
8 | | Dielectric 3 | FR-4 | 8mil | 4.4
9 | | Layer 3 | CF-004 | 0.689mil
10 | | Dielectric 4 | FR-4 | 2.3mil | 4.4
11 | | Layer 4 | CF-004 | 0.689mil
12 | | Dielectric 5 | Taconic TLX-8 | 5mil | 2.55
13 | | Bottom Layer | | 0.354mil
14 | | Bottom Solder | Solder Resist | 0.4mil | 3.5
15 | | Bottom Overlay | | 0mil

Height : 26.864mil





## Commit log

2025-10-22 Add initial content to Packages.md
    I will use this to upload PCBO packages
2025-10-22 Enhance README with PCB order package details
    Added detailed description of PCB order package contents.
2025-10-22 Revise Antennas.md with LaTeX formatting and details
    Updated formatting and added details for B^3 antenna designs.
    - This is not completed yet.
2025-10-25 Add Rx antenna design details for B^3
    This chapter describes the design and characteristics of a single rectangular microstrip patch receive antenna used in $B^3$, including electromagnetic modeling, dimensions, and impedance matching.
2025-10-25 Revise patch antenna design and performance details
    Updated the description of the patch antenna design, including details on impedance matching and performance metrics.
2025-10-25 Update formatting for PCB Order Package title
2025-10-25 Antenna design concluded
    Updated descriptions and figures for Rx and Tx antennas. Improved clarity on antenna performance and design specifications.
2025-10-26 Revise hardware description and PCBO documentation
    Updated hardware description and repository structure details.
2025-10-26 Fix typo in Tx antenna description
2025-10-26 Add new file 'aa' in BILL OF MATERIALS directory
2025-10-26 Update README with new documentation directories
    Added documentation directories for BOM and manufacturing.
2025-10-29 Change inset feed impedance from 100Ω to 70.7Ω
2025-10-29 Revise impedance matching from 50Ω to 70.7Ω
    Updated impedance matching details for the antenna design.
2025-10-29 Enhance documentation for Hadamard matrix and coupler
    Added detailed descriptions of the Hadamard matrix and quadrature hybrid coupler, including diagrams and S-parameter analysis for various port excitations.
2025-11-01 Update print statement from 'Hello' to 'Goodbye'
